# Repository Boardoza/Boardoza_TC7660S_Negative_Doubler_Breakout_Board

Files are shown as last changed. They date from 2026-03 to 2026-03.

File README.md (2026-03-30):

# Boardoza TC7660S Negative Doubler Breakout Board

The **Boardoza TC7660S Negative Doubler Breakout Board** is a compact voltage conversion solution based on the **TC7660S** charge pump IC. It is designed to generate a **stable negative voltage (-VOUT)** and a  **doubled negative voltage (-2VOUT)** from a positive input supply without requiring inductors.

Using a switched-capacitor voltage converter architecture, this board efficiently inverts and doubles the input voltage, making it ideal for low-current precision analog applications. It is especially well-suited for powering operational amplifiers, sensor signal conditioning circuits, and instrumentation systems where a clean and stable negative supply is required. With a typical output capability of up to **10 mA**, it is optimized for reference and low-power analog designs rather than high-current loads.

## [Click here to purchase!](https://www.ozdisan.com/ureticiler/boardoza)
| Front Side | Back Side |
| :---: | :---: |
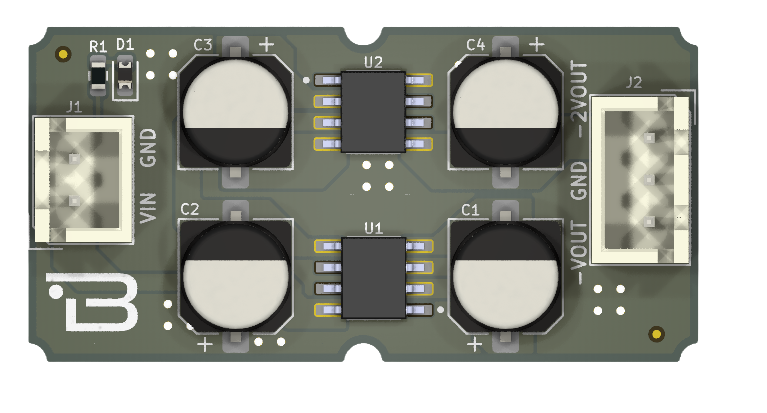
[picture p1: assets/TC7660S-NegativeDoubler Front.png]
Front
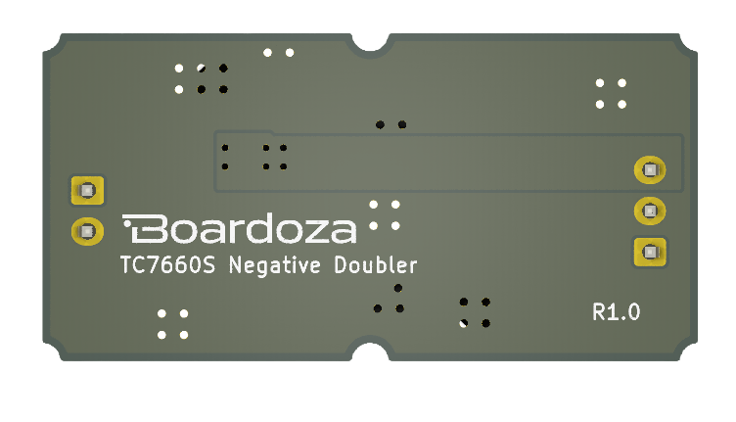
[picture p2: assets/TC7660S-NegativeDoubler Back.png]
Back
|  |  |

---

## Key Features

- **Negative Voltage Generation:** Converts a single positive supply into stable negative voltage outputs.
- **Dual Output Capability:** Provides both -VOUT and -2VOUT options for flexible circuit design.
- **High Efficiency Charge Pump:** Achieves very high efficiency under light load conditions.
- **Low Power Consumption:** Optimized for precision, low-current applications.
- **Precision Focused Design:** Ideal for clean and stable reference voltage generation.

---

## Technical Specifications

**Model:** TC7660S-NegativeDoubler  
**Manufacturer:** Boardoza   
**Manufacturer IC:** Microchip Technology Inc.  
**Functions:** Negative voltage regulator  
**Input Voltage:** 1.5 V – 12 V  
**Voltage Input Type:** 2.50 mm pin header  
**Output Current:** 10 mA  
**Conversion Type:** Switched-capacitor charge pump  
**Oscillator Frequency:** Between 10 kHz to 45 kHz    
**Efficiency:** Up to 98–99% (typical, light load)  
**Operating Temperature:** -40 °C to +80 °C  
**Board Dimensions:** 40 mm × 20 mm

---

## Board Pinout

### ( J1 ) Power Input Connector

| Pin Number | Pin Name | Description |
| --- | --- | --- |
| 1 | VIN | Positive input voltage (1.5V – 12V) |
| 2 | GND | Ground |

### ( J2 ) Output Connector

| Pin Number | Pin Name | Description |
| --- | --- | --- |
| 1 | -2VOUT | Negative output, twice the input voltage |
| 2 | GND | Ground |
| 3 | -VOUT | Negative output, equal to input voltage |

---

## Board Dimensions

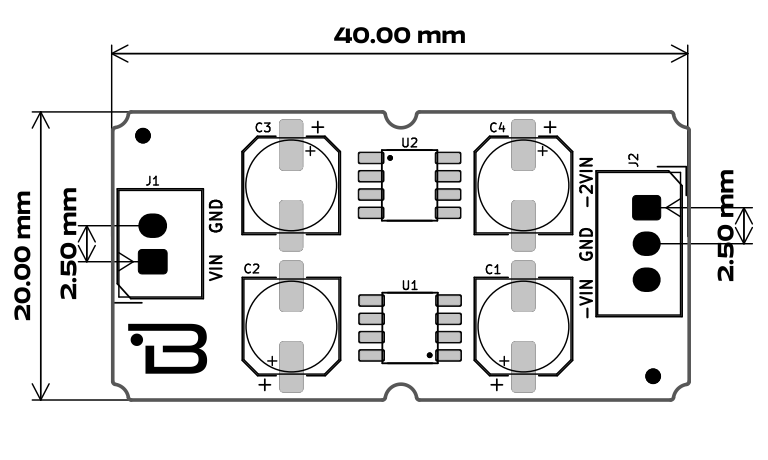
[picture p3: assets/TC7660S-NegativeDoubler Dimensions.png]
Board Dimensions


---

## Step Files

[Boardoza TC7660S-NegativeDoubler.step](./assets/TC7660S-NegativeDoubler%20Step.step)

---

## Datasheet

[TC7660S Datasheet.pdf](./assets/TC7660S-NegativeDoubler%20Datasheet.pdf)

---

## Version History

- V1.0.0 – Initial Release

---

## Support

- If you have any questions or need support, please contact **support@boardoza.com**

---

## **License**
### **Hardware Design**

[][cc-by-sa]

All hardware design files are licensed under [Creative Commons Attribution-ShareAlike 4.0 International License][cc-by-sa].

[cc-by-sa]: http://creativecommons.org/licenses/by-sa/4.0/
[cc-by-sa-shield]: https://img.shields.io/badge/License-CC%20BY--SA%204.0-lightgrey.svg

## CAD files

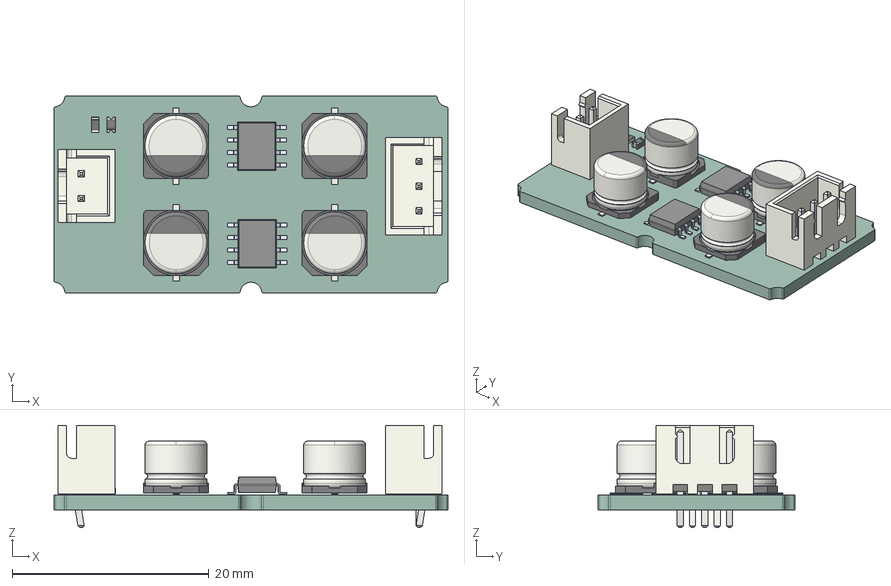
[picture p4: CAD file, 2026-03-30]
assets/TC7660S-NegativeDoubler Step.step
40.0 x 20.0 x 10.4 mm
TC7660SEOA713 x 2
JST_XH_B3B-XH-A_1x03_P2.50mm_Vertical
CP_Elec_6.3x5.4 x 4
JST_XH_B2B-XH-A_1x02_P2.50mm_Vertical
D_0603_1608Metric
R_0603_1608Metric
B-TC7660S-BRK-NegativeDoubler_PCB

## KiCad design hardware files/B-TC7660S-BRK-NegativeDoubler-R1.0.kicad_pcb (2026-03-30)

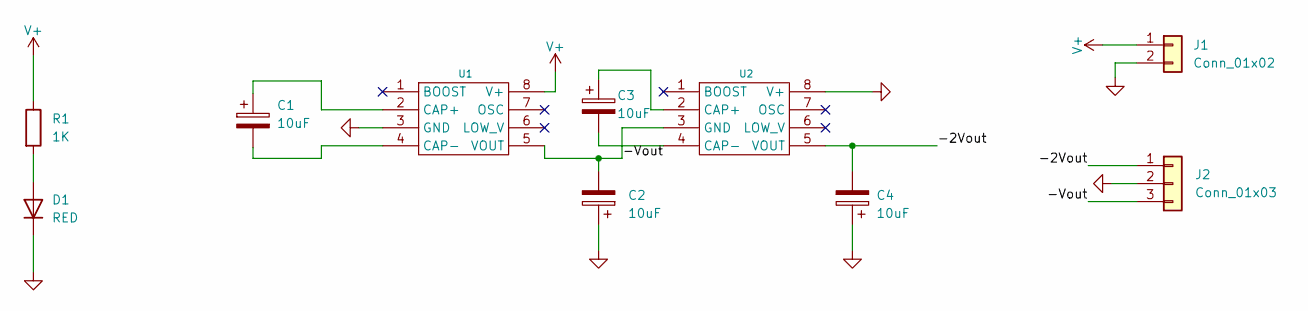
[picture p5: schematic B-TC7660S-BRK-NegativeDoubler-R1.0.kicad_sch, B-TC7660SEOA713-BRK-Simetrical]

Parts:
C1, C2, C3, C4: 10uF; CP_Elec_6.3x5.4; MPN JCS1H100M063054
D1: RED; D_0603_1608Metric; MPN LTST-C190KRKT
J1: Conn_01x02; 2317-02S_1x02_P2.50mm_Vertical; MPN 2317-02S
J2: Conn_01x03; 2317-03S_1x03_P2.50mm_Vertical; MPN 2317-03S
R1: 1K; R_0603_1608Metric; MPN PS03W4F1001T5E
U1, U2: SOIC127P599X175-8N; MPN TC7660SEOA713

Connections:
/-2Vout: C4.2, J2.1, U2.5 (VOUT)
/-Vout: C2.2, J2.3, U1.5 (VOUT), U2.3 (GND)
GND: C2.1, C4.1, D1.1 (K), J1.2, J2.2, U1.3 (GND), U2.8 (V+)
unnamed: D1.2 (A), R1.2
unnamed: C1.1, U1.2 (CAP+)
unnamed: C1.2, U1.4 (CAP-)
unnamed: C3.1, U2.2 (CAP+)
unnamed: C3.2, U2.4 (CAP-)
V+: J1.1, R1.1, U1.8 (V+)

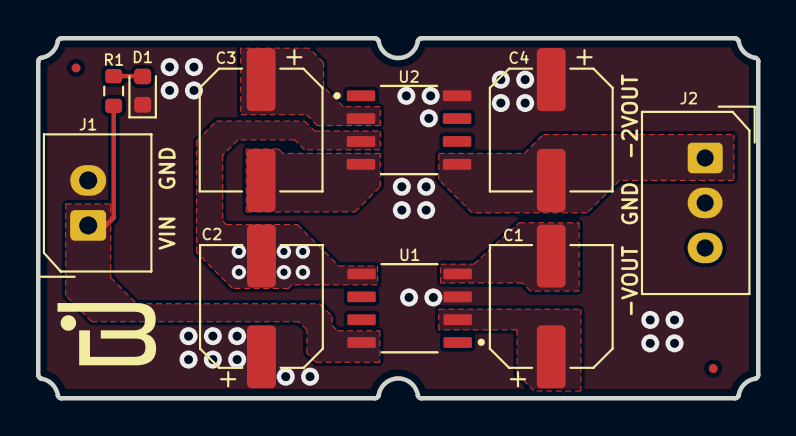
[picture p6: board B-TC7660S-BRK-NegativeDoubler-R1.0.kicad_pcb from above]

Board: 2 copper layers, 40.0 x 20.0 mm, 10 parts (0 on the bottom side), 9 nets.

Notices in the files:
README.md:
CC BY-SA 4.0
